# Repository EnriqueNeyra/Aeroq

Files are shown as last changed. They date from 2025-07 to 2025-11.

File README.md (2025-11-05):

# Aeroq



### A comprehensive indoor air quality monitor, capturing Temperature, Relative Humidity, CO2 (ppm), VOC (Index), and PM 1.0, 2.5, 4.0, 10 (ug/m3)

## Contents
- [Project Overview](#project-overview)
- [Required Hardware](#required-hardware)
- [Firmware Setup](#firmware-setup)
- [Assembly](#assembly)
- [Using Aeroq](#using-aeroq)

---
## Project Overview

### Hardware
Schematic and PCB designed using KiCad. Schematic, PCB design, and manufacturing files can be found under [Aeroq Hardware/](./Aeroq%20Hardware/v3)



### Enclosure
Two 3D printed components are required for the assembly. Model files can be found under [Aeroq Enclosure/](./Aeroq%20Enclosure)



### Firmware
Source code for ESP32 firmware, developed with PlatformIO. Can be found under [Aeroq Firmware/](./Aeroq%20Firmware)

---

## Required Hardware  

| Item | Link |
|---|---|
| Custom PCB Order | [PCBWay](https://www.pcbway.com/project/shareproject/Air_Quality_Monitor_a6b051c5.html) |
| SEN54 (VOC/PM) Sensor | [Sensirion](https://sensirion.com/products/catalog/SEN54) |
| Enclosure 3D Print Files | [Printables](https://www.printables.com/model/1394330-indoor-air-quality-monitor) |
| 3.7" 240x416 E-Paper Display | [GoodDisplay](https://buyepaper.com/products/37-inch-416x240-e-paper-black-and-white-spi-fast-refresh-electronic-eink-display-screen-esl-gdey037t03) |
| JST GH 6 Pin Connector | [Adafruit](https://www.adafruit.com/product/5754#description) |

---

## Firmware Setup

This project uses [PlatformIO](https://platformio.org/), a plugin for VSCode that streamlines ESP32 development. The firmware is written in C++ and targets the **ESP32-C3** microcontroller.  

### Steps

1. **Install VSCode**  
   Download and install [Visual Studio Code](https://code.visualstudio.com/).

2. **Install PlatformIO**  
   In VSCode, open the Extensions tab (`Ctrl+Shift+X`), search for **PlatformIO IDE**, and install it.

3. **Clone this Repository**  
   ```bash
   git clone https://github.com/EnriqueNeyra/Aeroq.git
   cd "Aeroq/Aeroq Firmware"

4. **Open Project in PlatformIO**  
   - In VSCode, go to *File > Open Folder*  
   - Select the `Aeroq Firmware/` directory.  

5. **Connect the ESP32-S3**  
   - Use a USB-C cable to connect the board to your computer.  
   - Ensure the correct COM port/device is available  
   - The *monitor_port* configuration value may need to be changed in the platformio.ini file  

6. **Build and Upload**  
   In PlatformIO, use the toolbar at the bottom:  
   - **Build**: Compile the firmware  
   - **Upload**: Flash firmware to the ESP32-C3  

7. **Monitor Serial Output (Optional)**  
   - Use the PlatformIO **Serial Monitor** to view sensor readings  
   - Default baud rate: `115200`

---

## Assembly

### 1. Components should connect as pictured below
<p align="center"><img src="https://github.com/user-attachments/assets/5740bab2-e6b4-4e19-9f66-7cb31afb2b5f" width="700"></p>

### 2. Insert the SEN54 into the slot in the enclosure, ensuring it is pressed in all the way
<p align="center"><img src="https://github.com/user-attachments/assets/f272257f-dbc3-4e41-ade8-5990a57cf071" width="700"></p>

### 3. Place display into frame
<p align="center"><img src="https://github.com/user-attachments/assets/dd597183-dd0e-4cfe-8b03-1174462b1bcc" width="700"></p>

### 4. Orient the PCB so that it sits against the back of the display. This CAD assembly image illustrates the correct component orientation
<p align="center"><img src="https://github.com/user-attachments/assets/d5072620-c4a7-4da5-b4a5-5fcc545736fb" width="700"></p>

### 5. Press the enclosure shut. The USB-C port should be visible and accessible through the slot at the rear
<p align="center"><img src="https://github.com/user-attachments/assets/f5b62217-b6d0-4359-aae4-ba4664226a09" width="700"></p>

---

## Using Aeroq

Simply plug the device in using any USB-C cable/power supply (minimum 5V 1A), and wait for the initialization to complete.  
**For optimal measurement accuracy, keep it away from heat sources (electronics, lights, etc) and in an area with minimal clutter.**

<img width="2268" height="1181" alt="image" src="https://github.com/user-attachments/assets/763cf77f-df35-4627-929d-93a298740765" />

## License

This project (hardware, design files, and firmware) is licensed under the 
[Creative Commons Attribution-NonCommercial-ShareAlike 4.0 International License](http://creativecommons.org/licenses/by-nc-sa/4.0/).

[![License: CC BY-NC-SA 4.0](https://licensebuttons.net/l/by-nc-sa/4.0/88x31.png)](http://creativecommons.org/licenses/by-nc-sa/4.0/)

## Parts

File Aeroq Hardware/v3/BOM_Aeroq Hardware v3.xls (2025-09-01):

Designator | Quantity | Value | Footprint | Package | MPN | DNP | Mount_Type | Description | Manufacturer Part | Manufacturer | Supplier Part | Supplier | LCSC Part Name | MF | MAXIMUM_PACKAGE_HEIGHT | Price | Check_prices | STANDARD | PARTREV | SnapEDA_Link | MP | Description_1 | Availability | MANUFACTURER | SNAPEDA_PN
C1, C6, C9 | 3 | 10uf/25V | C_0603_1608Metric |  |  |  | smt | Unpolarized capacitor
C10, C12, C13, C14, C16, C17, C18, C19, C23, C24 | 10 | 4.7uf/25V | C_0603_1608Metric |  |  |  | smt | Unpolarized capacitor
C11, C15, C2, C3, C5, C7, C8 | 7 | 0.1uf/50V | C_0603_1608Metric |  |  |  | smt | Unpolarized capacitor
C20, C21, C22, C25, C4 | 5 | 1uf/50V | C_0603_1608Metric |  |  |  | smt | Unpolarized capacitor
D1 | 1 | 1N5819WS | D_SOD-323 |  |  |  | smt | 40V 600mV@1A 1A SOD-323 Schottky Barrier Diodes, SOD-323
D2, D3, D4 | 3 | ~ | SOD-523_L1.2-W0.8-LS1.6-BI |  |  |  | tht | polarity:Bidirectional Reverse Stand-Off Voltage (Vrwm):5V Maximum Clamping Voltage:18.6V Peak Pulse Current (Ipp):9.4A Breakdown Voltage:5.6V Type:ESD | LESD5D5.0CT1G | LRC(乐山无线电) | C383211 | LCSC | 双向ESD
D5, D6, D7 | 3 | MBR0530 | D_SOD-123 |  |  |  | smt | 30V 0.5A Schottky Power Rectifier Diode, SOD-123
FPC1 | 1 | ~ | FPC-SMD_24P-P0.50_FPC-05FB-24PH20 |  |  |  | tht | Locking Feature:Clamshell Contact Type:Double-sided contacts/up and down connection Number of Contacts:24P Pitch:0.5mm Mounting Type:卧贴 FFC, FCB Thickness:0.3mm FFC, FCB Thickness:0.3mm Height Above Board:2mm Operating Temperature Range:-25°C~+85°C Operatin | FPC-05FB-24PH20 | XUNPU(讯普) | C2856831 | LCSC | 间距:0.5mm P数:24P 翻盖式 双侧触点/上下接
L1 | 1 | 10uH/1A | L_1210_3225Metric |  |  |  | smt | Inductor
Q1 | 1 | Si1308EDL | SOT-323_SC-70 |  |  |  | smt | 30V Vds, 1.4A Id, N-Channel MOSFET, SC-70
R1, R2, R5, R6, R9 | 5 | 10k | R_0402_1005Metric |  |  |  | smt | Resistor
R10 | 1 | 0.47 | R_0402_1005Metric |  |  |  | smt | Resistor
R3, R4 | 2 | 5k | R_0402_1005Metric |  |  |  | smt | Resistor
R7 | 1 | 3 | R_0402_1005Metric |  |  |  | smt | Resistor
SW1, SW2 | 2 | ~ | SW-SMD_L3.9-W3.0-P4.45 |  |  |  | tht | Circuit:SPST Actuator Style:Round Button Operating Force:160gf Mounting Style:Brick nogging Switch Length:4mm Switch Width:3mm Switch Height:2mm Strike Gundam:不带 Contact Current:50mA Voltage Rating (DC):12V Insulation Resistance:100MΩ Actuator/Cap Color:B | TS-1088-AR02016 | XUNPU(讯普) | C720477 | LCSC | 4*3*2mm 立贴 轻触开关
TP1, TP2, TP3, TP4, TP5 | 5 | TestPoint | TestPoint_Pad_D1.5mm |  |  |  | tht | test point
U1 | 1 | ~ | TYPE-C-SMD_USB4120-03-C |  |  |  | tht | Connector Type:Type-C Standard:USB 3.1 Gender:Female Mounting Style:Standing paste Number of Contacts:16P Number of Ports:1 Current Rating - Power (Max):5A Contact Material:- Contact Plating:- Operating Temperature Range:-40°C~+85°C Operating Temperature Ra | TYPE-C 16PLT-H10.0 | SHOU HAN(首韩) | C3151749 | LCSC | Type-C 母 立贴
U2 | 1 | ESP32-C3-MINI-1-N4 | XCVR_ESP32-C3-MINI-1-N4 | SMD-53 Espressif Systems |  |  | smt |  |  |  |  |  |  | Espressif Systems | 2.55mm | None | https://www.snapeda.com/parts/ESP32-C3-MINI-1-N4/Espressif+Systems/view-part/?ref=eda | Manufacturer Recommendations | v1.0 | https://www.snapeda.com/parts/ESP32-C3-MINI-1-N4/Espressif+Systems/view-part/?ref=snap | ESP32-C3-MINI-1-N4 | Bluetooth, WiFi 802.11b/g/n, Bluetooth v5.0 Transceiver Module 2.412GHz ~ 2.484GHz PCB Trace Surface Mount | In Stock | Espressif Systems
U3 | 1 | AMS1117-3.3 | SOT-223-3_TabPin2 |  |  |  | smt | 1A Low Dropout regulator, positive, 3.3V fixed output, SOT-223
U4 | 1 | SCD40-D-R1 | XDCR_SCD40-D-R1 | None |  |  | smt |  |  |  |  |  |  | Sensirion AG | 6.8mm | None | https://www.snapeda.com/parts/SCD40-D-R1/Sensirion/view-part/?ref=eda | Manufacturer Recommendations | 1.2 | https://www.snapeda.com/parts/SCD40-D-R1/Sensirion/view-part/?ref=snap | SCD40-D-R1 | Carbon Dioxide (CO2), Humidity, Temperature Sensor I2C | In Stock | Sensirion | SCD41-D-R2
U5 | 1 | ~ | CONN-SMD_6P-P1.25_XUNPU_WAFER-GH1.25-6PWB |  |  |  | tht | Pins Structure:1x6P Pitch:1.25mm Mounting Type:Horizontal attachment Reference Series:GH Number of Pins:6P Number of Rows:1 Number of PINs Per Row:6 Row Spacing:- Current Rating:1A Contact Material:Brass Contact Plating:- Operating Temperature:-25°C~+85°C O | WAFER-GH1.25-6PWB | XUNPU(讯普) | C3029381 | LCSC | 1x6P 间距:1.25mm 卧贴 系列:GH

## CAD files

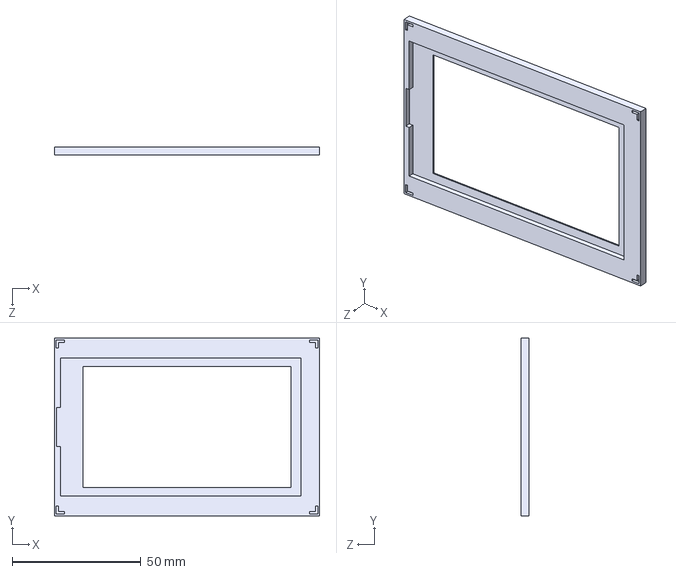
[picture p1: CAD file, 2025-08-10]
Aeroq Enclosure/Display Holder.STEP
103.0 x 69.0 x 3.00 mm

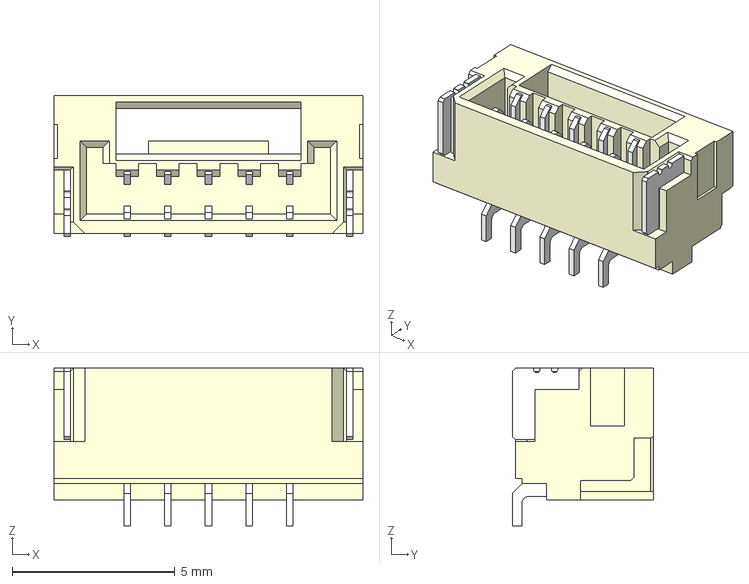
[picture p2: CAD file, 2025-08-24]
Aeroq Hardware/v3/Models/SM05B-GHS-TB-LF--SN---3DModel-STEP-469947.STEP
9.50 x 4.35 x 4.85 mm

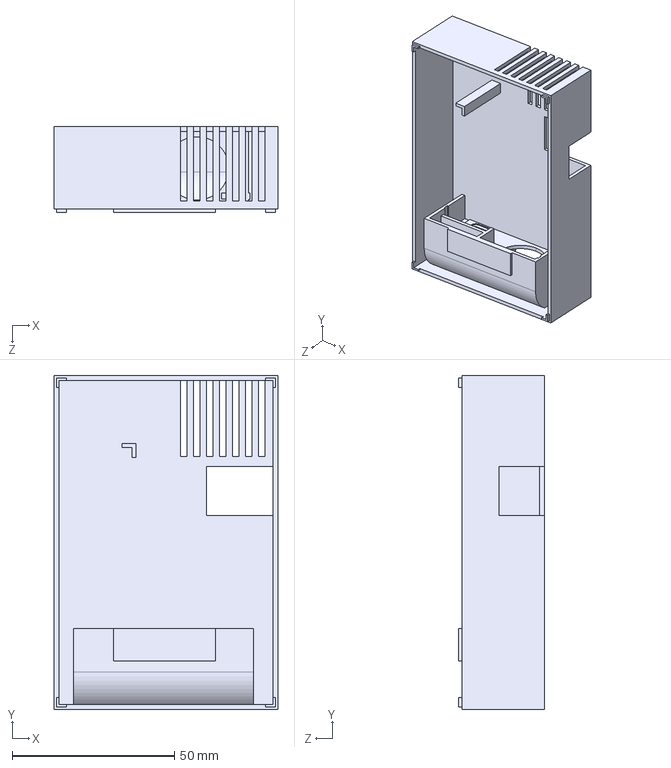
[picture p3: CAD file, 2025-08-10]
Aeroq Enclosure/Enclosure Base.STEP
69.0 x 103.0 x 26.5 mm

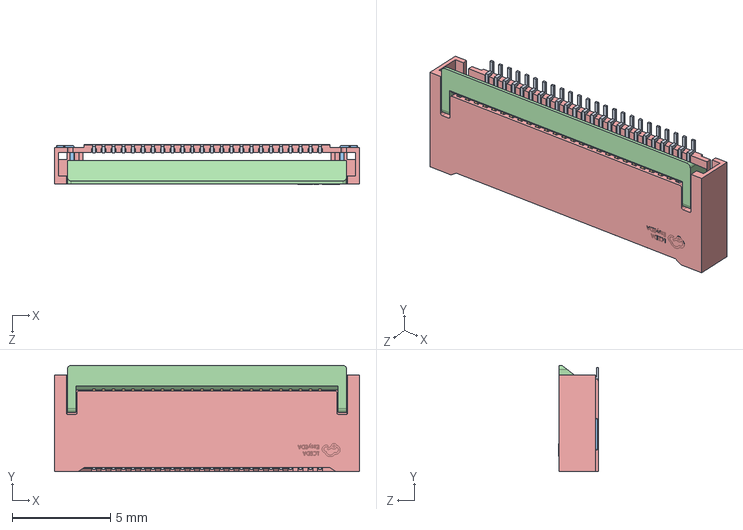
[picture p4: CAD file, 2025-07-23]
Aeroq Hardware/v3/Models/XUNPU FPC-05FB-24PH20.STEP
15.5 x 5.40 x 2.01 mm

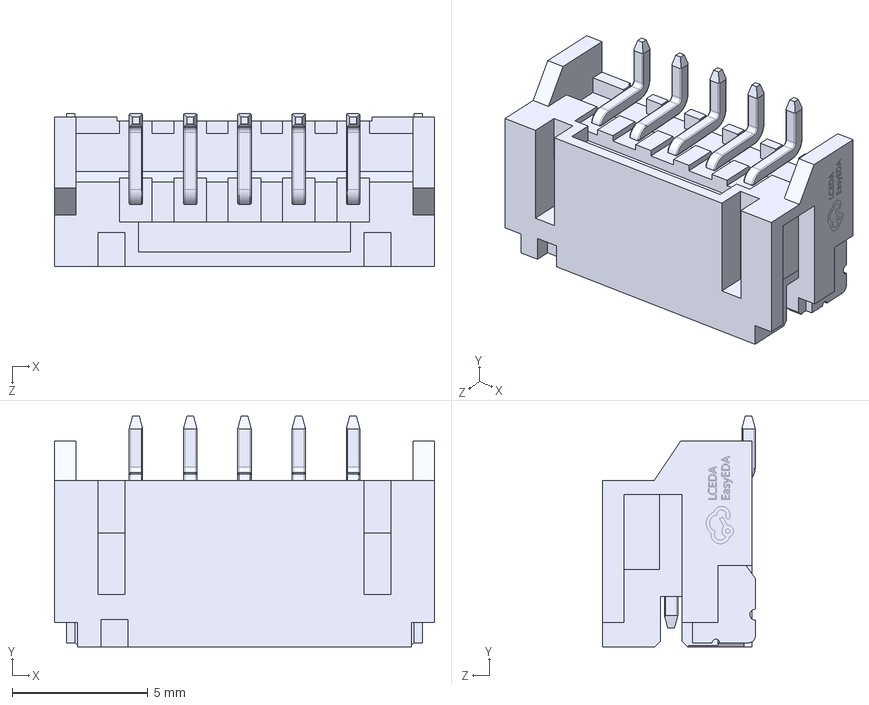
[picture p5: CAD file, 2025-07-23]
Aeroq Hardware/v3/Models/MEGASTAR ZX-PH2.0-WT5P.STEP
14.0 x 8.50 x 5.62 mm

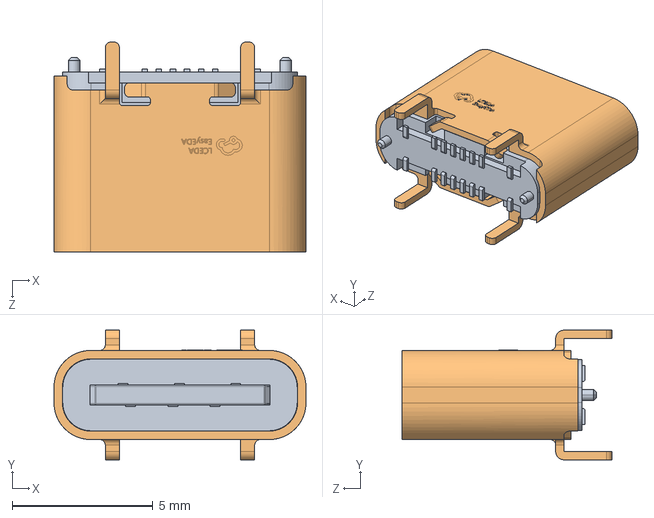
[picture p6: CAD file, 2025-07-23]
Aeroq Hardware/v3/Models/SHOU HAN TYPE-C 16PLT-H10.0.step
8.94 x 4.60 x 7.45 mm

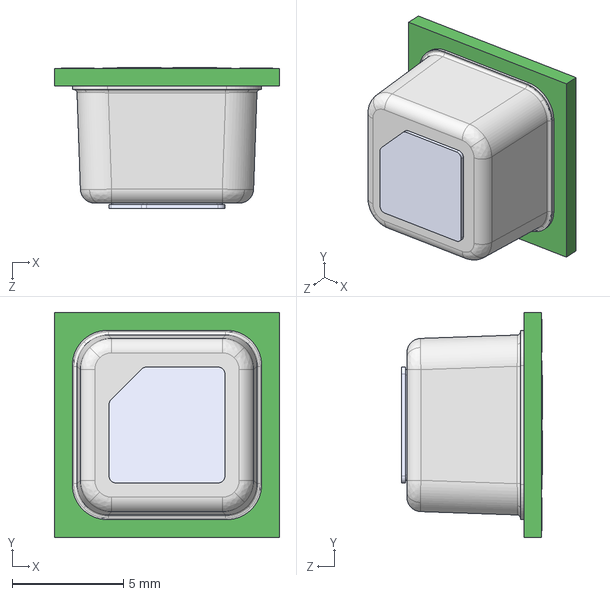
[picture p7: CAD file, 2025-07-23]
Aeroq Hardware/v3/Models/SCD40-D-R1--3DModel-STEP-369182.STEP
10.1 x 10.1 x 6.31 mm

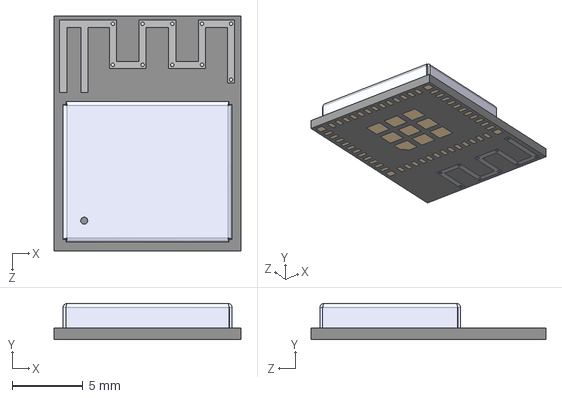
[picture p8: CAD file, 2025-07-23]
Aeroq Hardware/v3/Models/ESP32-C3-MINI-1-N4--3DModel-STEP-418109.STEP
13.2 x 2.55 x 16.6 mm

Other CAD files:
Aeroq Hardware/v3/Models/XUNPU FPC-05FB-24PH20_1.step.SLDASM
Aeroq Hardware/v3/Models/SHOU HAN TYPE-C 16PLT-H10.0_1.step.SLDASM
Aeroq Enclosure/CAD/Display Module.SLDPRT
Aeroq Enclosure/CAD/Display Holder.SLDPRT
Aeroq Enclosure/CAD/Enclosure Base.SLDPRT

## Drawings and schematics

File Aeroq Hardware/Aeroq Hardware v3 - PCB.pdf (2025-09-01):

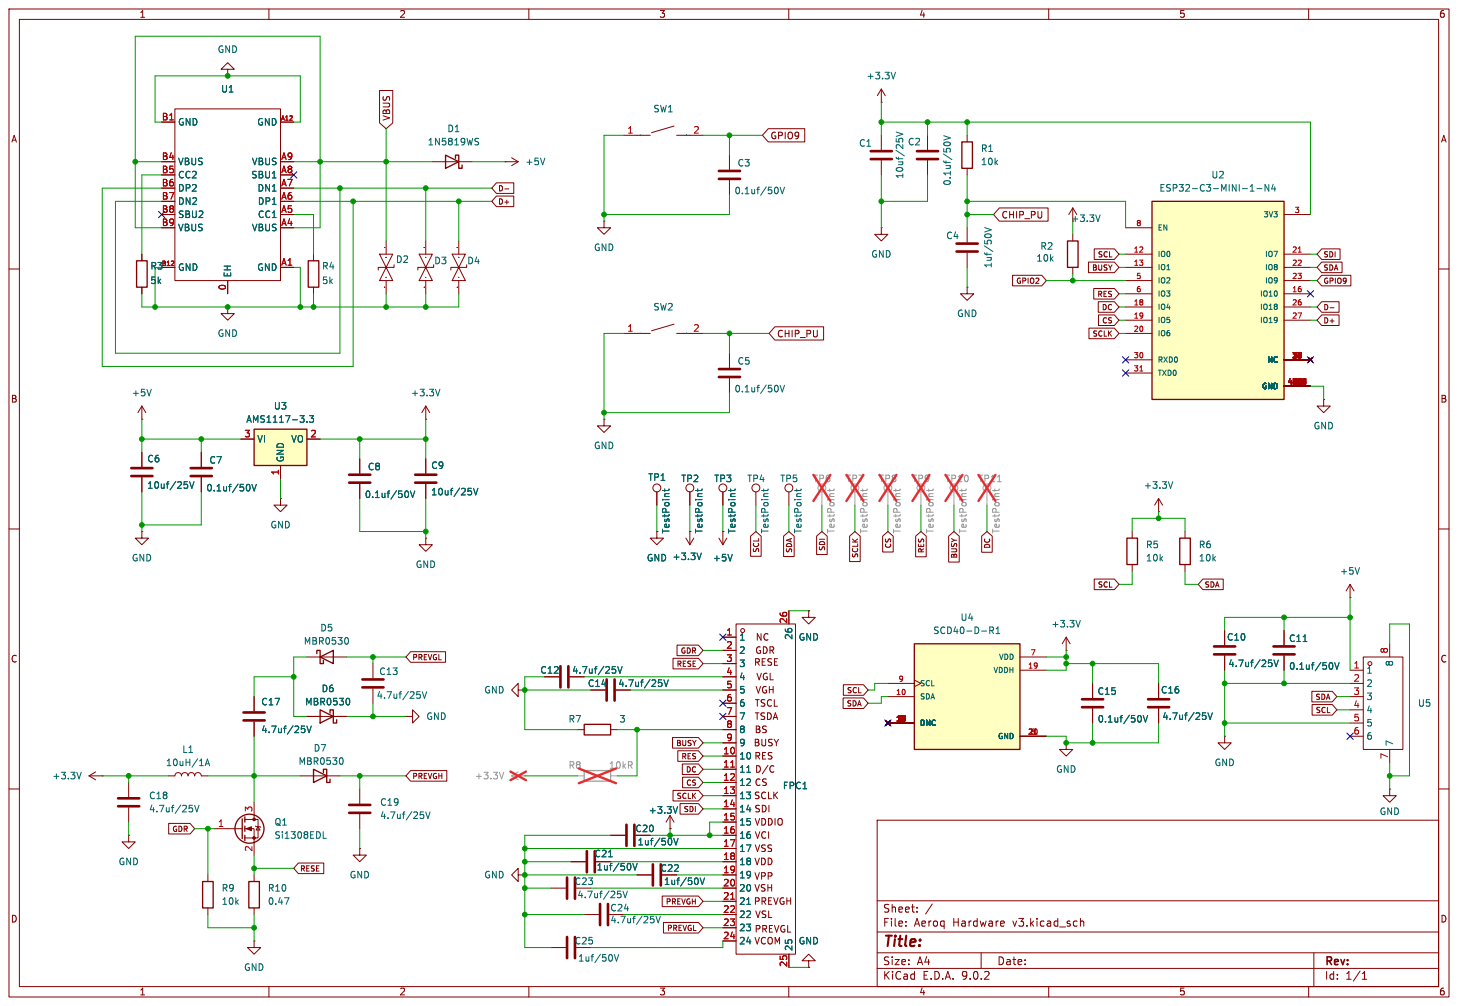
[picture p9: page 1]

0 GND A12 VBUS A9 SBU1 A8 DN1 A7 DP1 A6 CC1 A5 VBUS A4 GND A1 U1 TP7 TestPoint

0 GND A12 VBUS A9 SBU1 A8 DN1 A7 DP1 A6 CC1 A5 VBUS A4 GND A1 R3

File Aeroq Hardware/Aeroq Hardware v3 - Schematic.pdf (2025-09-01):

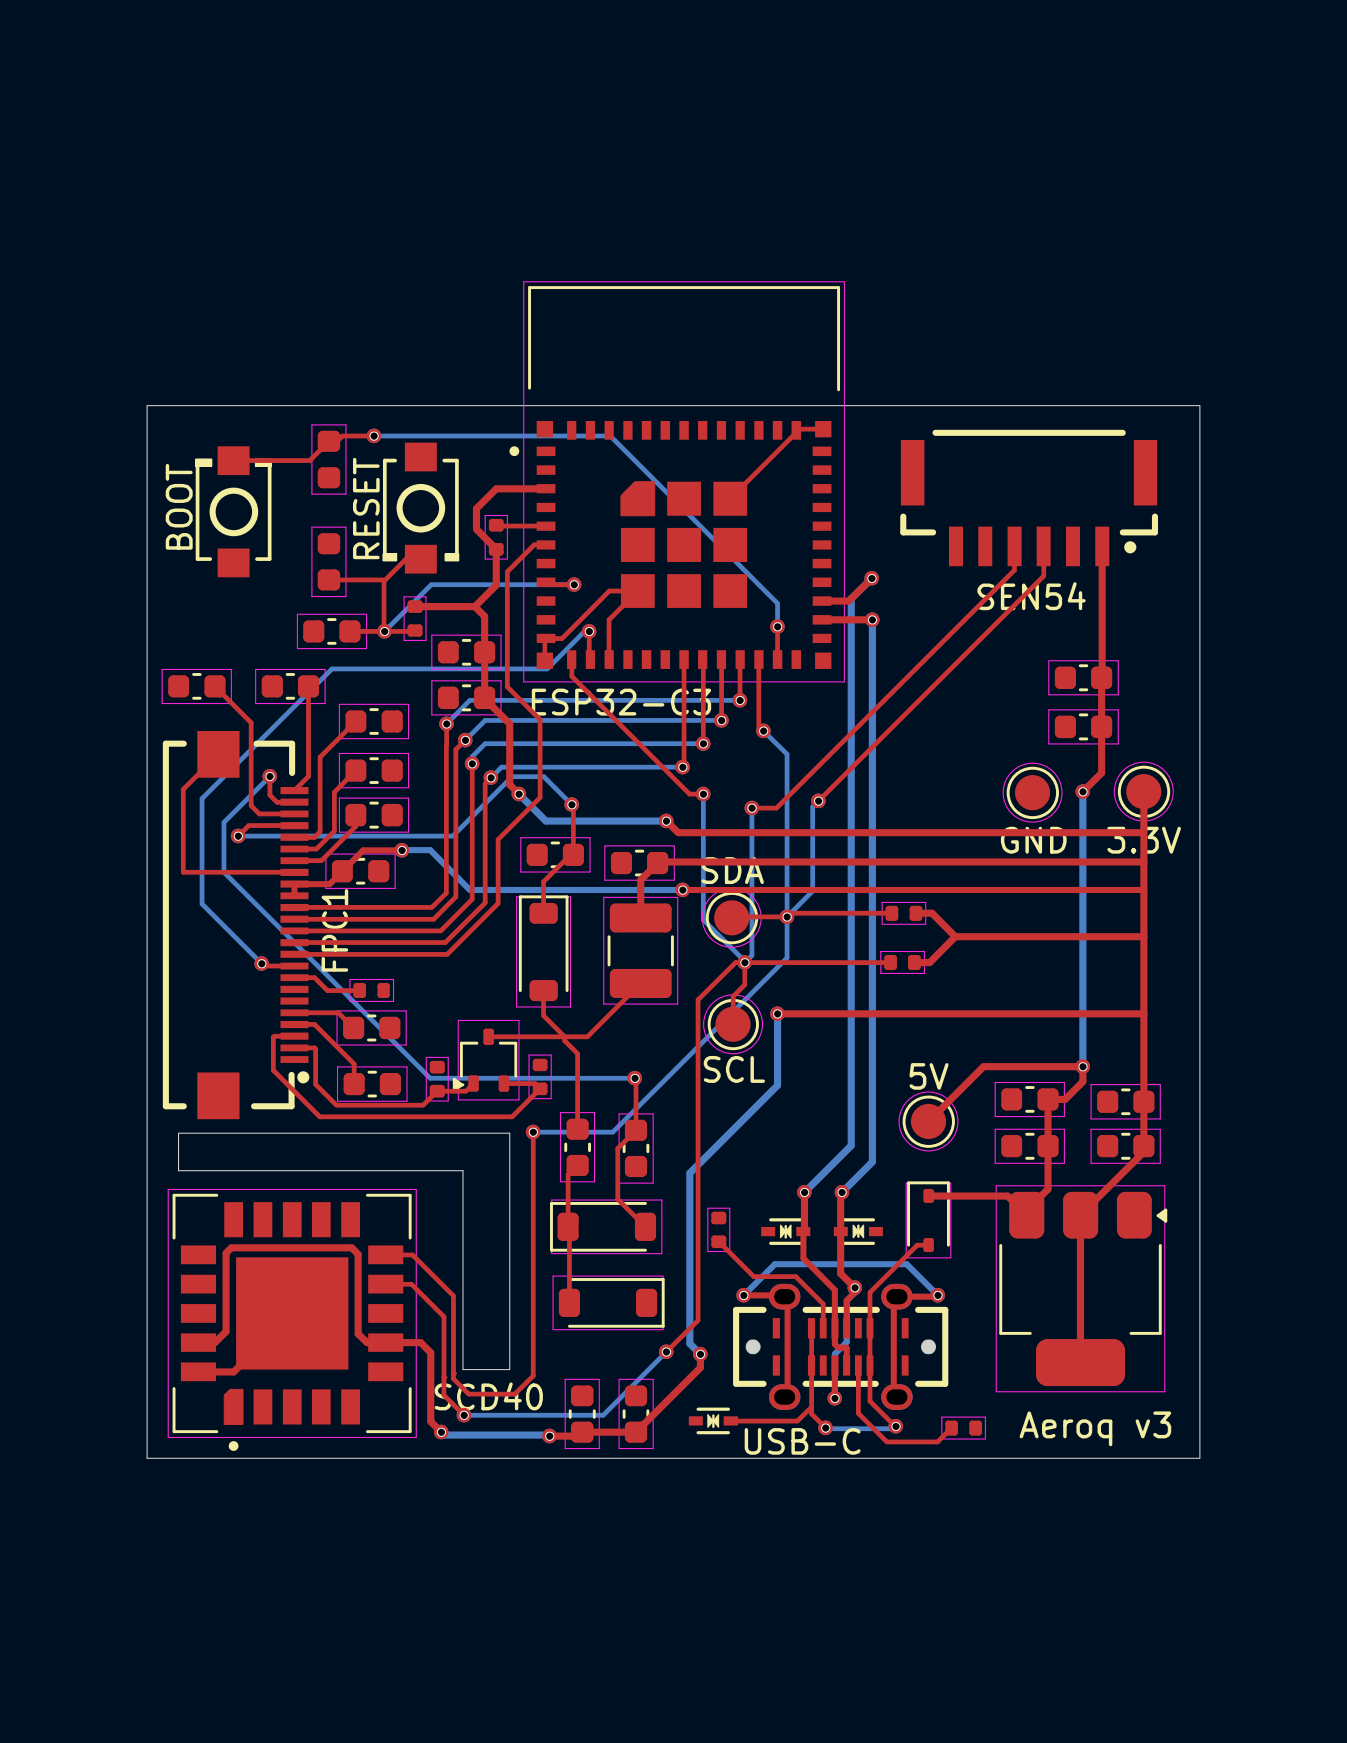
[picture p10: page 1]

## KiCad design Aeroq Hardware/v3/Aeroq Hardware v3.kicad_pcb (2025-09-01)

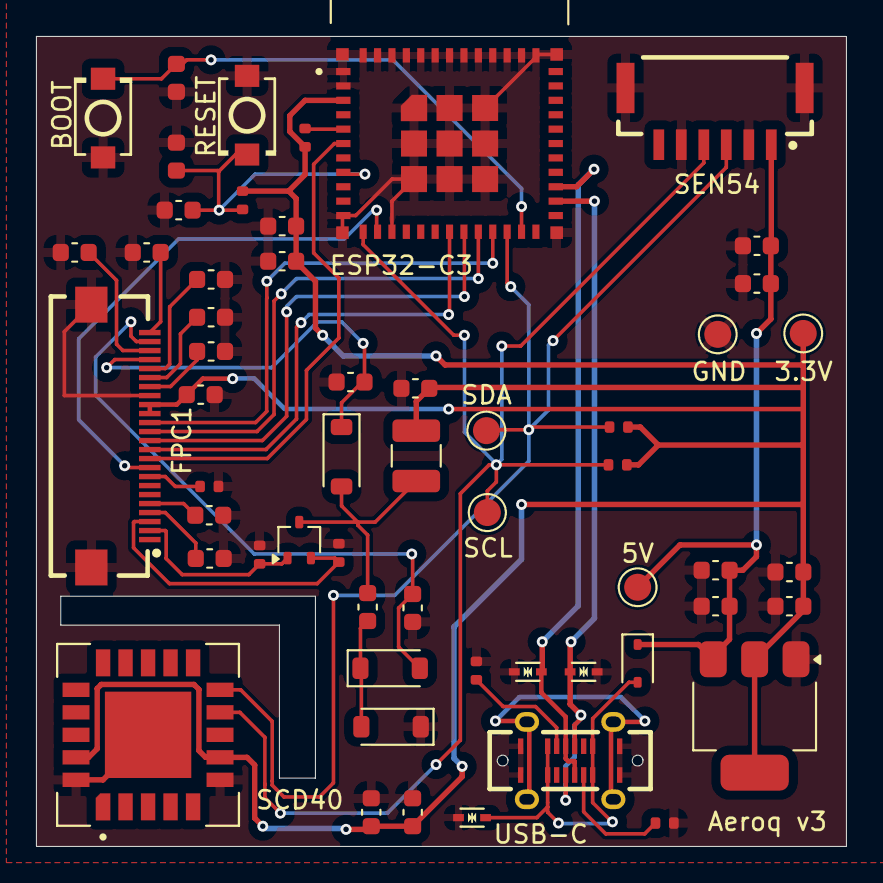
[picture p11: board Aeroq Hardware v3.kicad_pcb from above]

Board: 2 copper layers, 45.0 x 45.0 mm, 56 parts (0 on the bottom side), 33 nets.

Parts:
C1, C6, C9: 10uf/25V; C_0603_1608Metric
C2, C3, C5, C7, C8, C11, C15: 0.1uf/50V; C_0603_1608Metric
C4, C20, C21, C22, C25: 1uf/50V; C_0603_1608Metric
C10, C12, C13, C14, C16, C17, C18, C19, C23, C24: 4.7uf/25V; C_0603_1608Metric
D1: 1N5819WS; D_SOD-323
D2, D3, D4: SOD-523_L1.2-W0.8-LS1.6-BI
D5, D6, D7: MBR0530; D_SOD-123
FPC1: FPC-SMD_24P-P0.50_FPC-05FB-24PH20
L1: 10uH/1A; L_1210_3225Metric
Q1: Si1308EDL; SOT-323_SC-70
R1, R2, R5, R6, R9: 10k; R_0402_1005Metric
R3, R4: 5k; R_0402_1005Metric
R7: 3; R_0402_1005Metric
R10: 0.47; R_0402_1005Metric
SW1, SW2: SW-SMD_L3.9-W3.0-P4.45
TP1, TP2, TP3, TP4, TP5: TestPoint; TestPoint_Pad_D1.5mm
U1: TYPE-C-SMD_USB4120-03-C
U2: ESP32-C3-MINI-1-N4; XCVR_ESP32-C3-MINI-1-N4
U3: AMS1117-3.3; SOT-223-3_TabPin2
U4: SCD40-D-R1; XDCR_SCD40-D-R1
U5: CONN-SMD_6P-P1.25_XUNPU_WAFER-GH1.25-6PWB

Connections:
+3.3V: C1.2, C2.1, C8.1, C9.2, C15.1, C16.2, C18.1, C20.2, FPC1.15, FPC1.16, L1.1, R1.2, R2.2, R5.2, R6.2, TP2.1, U2.3 (3V3), U3.2 (VO), U4.7 (VDD), U4.19 (VDDH)
+5V: C6.2, C7.1, C10.2, C11.1, D1.1 (K), TP3.1, U3.3 (VI), U5.1
BUSY: FPC1.9, U2.13 (IO1)
CHIP_PU: C4.2, C5.1, R1.1, SW2.2, U2.8 (EN)
CS: FPC1.12, U2.19 (IO5)
D+: D4.2, U1.A6 (DP1), U1.B6 (DP2), U2.27 (IO19)
D-: D3.2, U1.A7 (DN1), U1.B7 (DN2), U2.26 (IO18)
DC: FPC1.11, U2.18 (IO4)
GDR: FPC1.2, Q1.1 (G), R9.2
GND: C1.1, C2.2, C3.2, C4.1, C5.2, C6.1, C7.2, C8.2, C9.1, C10.1, C11.2, C12.1, C13.2, C14.1, C15.2, C16.1, C18.2, C19.2, C20.1, C21.2, C22.2, C23.1, C24.1, C25.1, D2.1, D3.1, D4.1, D6.1 (K), FPC1.17, FPC1.25, FPC1.26, R3.1, R4.1, R7.2, R9.1, R10.1, SW1.1, SW2.1, TP1.1, U1.A1 (GND), U1.A12 (GND), U1.B1 (GND), U1.B12 (GND), U2.1 (GND), U2.2 (GND), U2.11 (GND), U2.14 (GND), U2.36 (GND), U2.37 (GND), U2.38 (GND), U2.39 (GND), U2.40 (GND), U2.41 (GND), U2.42 (GND), U2.43 (GND), U2.44 (GND), U2.45 (GND), U2.46 (GND), U2.47 (GND), U2.48 (GND), U2.49_1 (GND), U2.49_2 (GND), U2.49_3 (GND), U2.49_4 (GND), U2.49_5 (GND), U2.49_6 (GND), U2.49_7 (GND), U2.49_8 (GND), U2.49_9 (GND), U2.50 (GND), U2.51 (GND), U2.52 (GND), U2.53 (GND), U3.1 (GND), U4.6 (GND), U4.20 (GND), U4.21 (GND), U5.2, U5.5, U5.7, U5.8
GPIO2: R2.1, U2.5 (IO2)
GPIO9: C3.1, SW1.2, U2.23 (IO9)
unnamed: C12.2, FPC1.4
unnamed: C14.2, FPC1.5
unnamed: C21.1, FPC1.18
unnamed: C22.1, FPC1.19
unnamed: C23.2, FPC1.20
unnamed: C24.2, FPC1.22
unnamed: C25.2, FPC1.24
unnamed: C17.1, D5.1 (K), D6.2 (A)
unnamed: C17.2, D7.2 (A), L1.2, Q1.3 (D)
unnamed: FPC1.8, R7.1
unnamed: R4.2, U1.A5 (CC1)
unnamed: R3.2, U1.B5 (CC2)
PREVGH: C19.1, D7.1 (K), FPC1.21
PREVGL: C13.1, D5.2 (A), FPC1.23
RES: FPC1.10, U2.6 (IO3)
RESE: FPC1.3, Q1.2 (S), R10.2
SCL: R5.1, TP4.1, U2.12 (IO0), U4.9 (SCL), U5.4
SCLK: FPC1.13, U2.20 (IO6)
SDA: R6.1, TP5.1, U2.22 (IO8), U4.10 (SDA), U5.3
SDI: FPC1.14, U2.21 (IO7)
VBUS: D1.2 (A), D2.2, U1.A4 (VBUS), U1.A9 (VBUS), U1.B4 (VBUS), U1.B9 (VBUS)

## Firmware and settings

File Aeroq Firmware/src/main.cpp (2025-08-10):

#include <Arduino.h>
#include <Wire.h>
#include <SPI.h>
#include <SensirionI2CSen5x.h>
#include <SensirionI2cScd4x.h>
#include <GxEPD2_BW.h>
#include <Fonts/FreeSansBold12pt7b.h>
#include <Fonts/FreeSansBold18pt7b.h>
#include <Fonts/FreeSansBold24pt7b.h>

// ==== SPI + Display Pin Configuration ====
#define EPD_MOSI  7
#define EPD_SCK   6
#define EPD_CS    5
#define EPD_DC    4
#define EPD_RST   3
#define EPD_BUSY  1

#define SDA 8
#define SCL 0

// ==== GDEY037T03 e-paper display (416x240) ====
GxEPD2_BW<GxEPD2_370_GDEY037T03, GxEPD2_370_GDEY037T03::HEIGHT> display(
    GxEPD2_370_GDEY037T03(EPD_CS, EPD_DC, EPD_RST, -1));

// ==== Sensor Instances ====
SensirionI2CSen5x sen5x;
SensirionI2cScd4x scd41;

static char errorMessage[256];
static int16_t error;

#define NO_ERROR 0

void setup() {
    delay(1000);  // Delay to allow USB CDC setup
    Serial.begin(115200);
    unsigned long start = millis();
    while (!Serial && millis() - start < 1000) {
        delay(10);
    }
    Serial.println("===== Booting ESP32-S3 Air Quality Monitor =====");

    Wire.begin(SDA, SCL);
    Serial.println("Wire (I2C) initialized");

    // SPI pin remap
    SPI.begin(EPD_SCK, -1, EPD_MOSI);
    Serial.println("SPI initialized");

    // Init e-paper display
    Serial.println("Initializing display...");
    display.init(115200);
    display.setRotation(1);

    // Fully clear the screen before anything else
    display.setFullWindow();
    display.firstPage();
    do {
        display.fillScreen(GxEPD_WHITE);
    } while (display.nextPage());
    delay(1000);

    display.setFont(&FreeSansBold18pt7b);
    display.setTextColor(GxEPD_BLACK);
    // display.setFullWindow();
    display.firstPage();
    do {
        display.setCursor(120, 120);
        display.println("Initializing...");
    } while (display.nextPage());

    // Init SCD41
    Serial.println("Initializing SCD41...");
    scd41.begin(Wire, SCD41_I2C_ADDR_62);
    delay(30);
    error = scd41.wakeUp();
    Serial.printf("SCD41 wakeUp() -> %d\n", error);
    error = scd41.stopPeriodicMeasurement();
    Serial.printf("SCD41 stopPeriodicMeasurement() -> %d\n", error);
    error = scd41.reinit();
    Serial.printf("SCD41 reinit() -> %d\n", error);
    error = scd41.startPeriodicMeasurement();
    Serial.printf("SCD41 startPeriodicMeasurement() -> %d\n", error);

    // Init SEN54
    Serial.println("Initializing SEN54...");
    sen5x.begin(Wire);
    error = sen5x.deviceReset();
    Serial.printf("SEN54 deviceReset() -> %d\n", error);
    error = sen5x.setTemperatureOffsetSimple(0.0);
    Serial.printf("SEN54 setTemperatureOffsetSimple() -> %d\n", error);
    error = sen5x.startMeasurement();
    Serial.printf("SEN54 startMeasurement() -> %d\n", error);

    Serial.println("Setup complete.\n");
    delay(5000);

    // Clear the display again to ensure no old text remains
    display.setFullWindow();
    display.firstPage();
    do {
        display.fillScreen(GxEPD_WHITE);
    } while (display.nextPage());
}

void loop() {
    delay(5000); // 5s update cycle
    Serial.println("========== SENSOR UPDATE ==========");

    // ==== Read SCD41 ====
    Serial.println("[SCD41] Reading data...");
    bool dataReady = false;
    error = scd41.getDataReadyStatus(dataReady);
    if (error != NO_ERROR || !dataReady) {
        Serial.printf("[SCD41] getDataReadyStatus() error = %d\n", error);
        return;
    }

    uint16_t co2 = 0;
    float scdTemp = 0.0, scdRH = 0.0;
    error = scd41.readMeasurement(co2, scdTemp, scdRH);
    if (error != NO_ERROR) {
        Serial.printf("[SCD41] readMeasurement() error = %d\n", error);
        return;
    }

    Serial.printf("[SCD41] CO2: %d ppm\n", co2);
    Serial.printf("[SCD41] Temp: %.2f °C\n", scdTemp);
    Serial.printf("[SCD41] RH: %.2f %%\n", scdRH);

    // ==== Read SEN54 ====
    Serial.println("\n[SEN54] Reading data...");
    float pm1, pm2_5, pm4, pm10, senRH, senTemp, voc, nox;
    error = sen5x.readMeasuredValues(pm1, pm2_5, pm4, pm10, senRH, senTemp, voc, nox);
    if (error != NO_ERROR) {
        Serial.printf("[SEN54] readMeasuredValues() error = %d\n", error);
        return;
    }

    Serial.printf("[SEN54] Temp: %.2f °C, RH: %.2f %%\n", senTemp, senRH);
    Serial.printf("[SEN54] PM1.0: %.2f, PM2.5: %.2f, PM4.0: %.2f, PM10: %.2f ug/m3\n", pm1, pm2_5, pm4, pm10);
    Serial.printf("[SEN54] VOC Index: %.2f, NOx Index: %.2f\n", voc, nox);

    // ==== Averaged Values ====
    float avgTemp = (senTemp + scdTemp) / 2.0;
    float avgRH = (senRH + scdRH) / 2.0;

    // ==== Update Display ====
    Serial.println("\n[Display] Updating e-paper...");
    display.setPartialWindow(0, 0, display.width(), display.height());
    display.firstPage();
    do {
        display.fillScreen(GxEPD_WHITE);
        
        // First horizontal line
        display.drawLine(0, 102, 416, 102, GxEPD_BLACK);
        display.drawLine(0, 103, 416, 103, GxEPD_BLACK);

        // Vertical lines for Temp, RH, CO2, VOC
        display.drawLine(138, 0, 138, 102, GxEPD_BLACK);
        display.drawLine(139, 0, 139, 102, GxEPD_BLACK);

        display.drawLine(277, 0, 277, 102, GxEPD_BLACK);
        display.drawLine(278, 0, 278, 102, GxEPD_BLACK);

        // Horizontal lines for PM1.0, PM2.5, PM4.0, PM10
        display.drawLine(36, 148, 190, 148, GxEPD_BLACK);
        display.drawLine(226, 148, 380, 148, GxEPD_BLACK);
        display.drawLine(36, 194, 190, 194, GxEPD_BLACK);
        display.drawLine(226, 194, 380, 194, GxEPD_BLACK);

        // Bottom horizontal line
        display.drawLine(0, 215, 416, 215, GxEPD_BLACK);
        display.drawLine(0, 216, 416, 216, GxEPD_BLACK);
        
        display.setTextColor(GxEPD_BLACK);

        // Temperature and Humidity Display
        display.setFont(&FreeSansBold18pt7b);
        display.setCursor(20, 40);
        display.printf("%.1f C", avgTemp);

        display.setCursor(20, 90);
        display.printf("%.1f%%", avgRH);

        //Co2 and VOC Display
        display.setFont(&FreeSansBold12pt7b);
        display.setCursor(147, 25);
        display.printf("CO2 (ppm)");
        display.setFont(&FreeSansBold24pt7b);
        display.setCursor(165, 80);
        display.printf("%d", co2);
        
        display.setFont(&FreeSansBold12pt7b);
        display.setCursor(285, 25);
        display.printf("VOC Index");
        display.setFont(&FreeSansBold24pt7b);
        display.setCursor(310, 80);
        display.printf("%.0f", voc);

        // Particulate Matter Display
        display.setFont(&FreeSansBold12pt7b);
        display.setCursor(36, 146);
        display.printf("PM1:", pm1);
        display.setFont(&FreeSansBold18pt7b);
        display.setCursor(105, 146);
        display.printf("%.1f", pm1);

        display.setFont(&FreeSansBold12pt7b);
        display.setCursor(226, 146);
        display.printf("PM2.5:", pm2_5);
        display.setFont(&FreeSansBold18pt7b);
        display.setCursor(310, 146);
        display.printf("%.1f", pm2_5);

        display.setFont(&FreeSansBold12pt7b);
        display.setCursor(36, 192);
        display.printf("PM4:", pm4);
        display.setFont(&FreeSansBold18pt7b);
        display.setCursor(105, 192);
        display.printf("%.1f", pm4);

        display.setFont(&FreeSansBold12pt7b);
        display.setCursor(226, 192);
        display.printf("PM10:", pm10);
        display.setFont(&FreeSansBold18pt7b);
        display.setCursor(310, 192);
        display.printf("%.1f", pm10);

        //drawAirQualityIndicator(co2, voc, pm1, pm2_5, pm4, pm10);

    } while (display.nextPage());

    Serial.println("[Display] Refresh complete.\n");
}

// void drawAirQualityIndicator(uint16_t co2, float voc, float pm1, float pm2_5, float pm4, float pm10) {
//     bool isPoor = co2 > 1400 || voc > 250 || pm2_5 > 35 || pm10 > 50;
//     bool isModerate = co2 > 800 || voc > 120 || pm2_5 > 12 || pm10 > 20;

//     int16_t baseY = display.height() - 5;
//     int16_t triHeight = 10;
//     int16_t triWidth = 12;
//     int16_t halfWidth = triWidth / 2;

//     int16_t x;
//     if (isPoor) {
//         x = display.width() - 30;
//     } else if (isModerate) {
//         x = display.width() / 2;
//     } else {
//         x = 30;
//     }

//     display.fillTriangle(
//         x, baseY - triHeight,
//         x - halfWidth, baseY,
//         x + halfWidth, baseY,
//         GxEPD_BLACK);
// }

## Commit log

2025-06-09 Initial KiCad Files
    [Aeroq Hardware.kicad_pcb, Aeroq Hardware.kicad_sch]
2025-06-18 schematic and pcb initial
    [Aeroq Hardware.kicad_pcb, Aeroq Hardware.kicad_sch]
2025-06-27 add v2 PCB, add initial software files
    [Aeroq Hardware v2.kicad_pcb, Aeroq Hardware v2.kicad_sch, Aeroq Hardware.kicad_pcb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]
2025-07-23 Refactor ESP32-S3 Air Quality Monitor Code
    - Added lock files for PCB and schematic to track changes.
    - Updated platformio.ini to comment out the previous environment configuration and set up a new environment for esp32-c3-devkitm-1.
    - Modified main.cpp to enhance display functionality, including improved font sizes and layout for sensor readings.
    - Cleaned up commented-out code and organized the structure for better readability.
    - Implemented a more structured display update cycle with clear separation of sensor data.
    - Removed redundant code and improved comments for clarity.
    [Aeroq Hardware v2.kicad_pcb, Aeroq Hardware v3.kicad_pcb, Aeroq Hardware v3.kicad_sch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]
2025-08-10 Remove lock files and update platformio.ini and main.cpp for ESP32-S3 project
    - Deleted lock files for KiCad PCB and schematic to clean up project directory.
    - Changed monitor port from COM3 to COM4 in platformio.ini for correct serial communication.
    - Modified Serial initialization in main.cpp to include a timeout for better reliability during setup.
    [Aeroq Hardware v3.kicad_sch, Display Enclosure.SLDPRT, Display Enclosure.STEP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]
2025-08-11 Reorganize files, rename folders
    [Display Enclosure.SLDPRT, Display Holder.STEP, Display Module.SLDPRT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]
2025-08-11 Remove outdated PCB versions
    [Aeroq Hardware v2.kicad_pcb, Aeroq Hardware v2.kicad_sch, Aeroq Hardware.kicad_pcb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]
2025-08-24 updates to kicad schematic/pcb
    [Aeroq Hardware v3.kicad_pcb, Aeroq Hardware v3.kicad_sch, ESP32-C3-MINI-1-N4--3DModel-STEP-418109.STEP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]
2025-08-24 PCB Updates
    [Aeroq Hardware v3.kicad_pcb, Aeroq Hardware v3.kicad_sch]
2025-08-27 Add original solidworks CAD files and assembly
    [Display Holder.SLDPRT, Display Module.SLDPRT, Enclosure Base.SLDPRT]
2025-08-27 Add schematic+pcb pdf files for easier viewing
2025-09-01 KiCad schematic and PCB updates
    [Aeroq Hardware v3.kicad_pcb, Aeroq Hardware v3.kicad_sch, BOM_Aeroq Hardware v3.kicad_pcb.xls]
2025-09-01 Add updated schematic/pcb PDFs
    [BOM_Aeroq Hardware v3.xls]
2026-10-26 Point README to Aether and add troubleshooting
    Mark Aeroq as superseded by Aether. Document the SEN54 cable pin order,
    where the manufacturing files live, port auto-detection, and fixes for
    SEN54 error 270, low-voltage USB supplies, and failed uploads. Fix an
    unclosed code block and the ESP32-S3 typo.
2026-10-26 Keep the display updating when a sensor read fails
    A failed SEN54 or SCD4x read returned from loop() before drawing, leaving
    the screen blank. Keep the last readings, show "--" and a status line for
    a sensor that stops responding, and only skip the CO2 update when no new
    sample is ready.
    Also pass the BUSY pin to the display driver instead of fixed timeouts,
    do a full refresh every ~24h to clear ghosting, pin the official
    espressif32 platform, and drop the Windows-only monitor_port.
2026-10-26 Stop tracking KiCad backups, caches, and editor settings
2026-10-27 License firmware under GPL-3.0, keep hardware under CC BY-NC-SA
    The firmware links GxEPD2, which is GPL-3.0, so it can't carry a
    non-commercial restriction. Hardware and enclosure files stay CC BY-NC-SA 4.0.
